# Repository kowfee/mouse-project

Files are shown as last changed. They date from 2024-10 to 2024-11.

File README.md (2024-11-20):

# mouse-diy
this project was inspired by https://github.com/wareya/DIY-Gaming-Mouse

!!!! ----- DO NOT CHANGE THE STRUCTURE OF THE FILES AND DIRECTORIES IN 'mouse-diy' ---- !!!!

!!!! ----- src/srom_3360_0x04.h should contain copyrighted material, so it is not included in this repository. 0x00 should be replaced with a correct sequence, available on the internet ---- !!!!
!!!! ----- it is firmware for the pmw3360 sensor. it will function without the firmware, however loses some of the functionality and precision ---- !!!!

[INSTALLATION]

- Windows: 
    - within the 'dist' folder run the "installer.exe"

- Linux: 
    - run the following commands from the 'mouse-diy' directory in the terminal:
        - chmod 744 bin/arduino-cli
        - chmod 744 dist/interface
        - bin/arduino-cli core install arduino:mbed_rp2040@4.1.5
        - sudo $HOME/.arduino15/packages/arduino/hardware/mbed_rp2040/4.1.5/post_install.sh
        - bin/arduino-cli config set library.enable_unsafe_install true
        - bin/arduino-cli lib install --zip-path files/Adafruit_NeoPixel-1.12.3.zip

[HOW TO USE]

- Windows:
    - run the 'interface.exe' within the 'dist' folder

- Linux:
    - from the 'mouse-diy' directory run the following command:
        - dist/interface

The user interface lets you choose how many DPI settings you want to save and the DPI for each setting. You can also adjust the RGB color for the static setting.

[UNINSTALL]

- Windows: 
    - run the following commands in CMD:
        - rmdir /s /q %USERPROFILE%\AppData\Local\Arduino15\packages\arduino\hardware\mbed_rp2040\
        - rmdir /s /q %USERPROFILE%\Documents\Arduino\libraries\Adafruit_NeoPixel\

- Linux:
    - run the following commands in the terminal:
        - rm -rf $HOME/.arduino15/packages/arduino/hardware/mbed_rp2040/
        - rm -rf $HOME/Arduino/libraries/Adafruit_Neopixel/

[LICENSE]
Adafruit NeoPixel is licensed under GNU Lesser General Public License https://github.com/adafruit/Adafruit_NeoPixel

Arduino CLI is licensed under GNU General Public License https://github.com/arduino/arduino-cli

relmouse_16.h is based on files from mbed OS, also licensed under the Apache License, version 2.0. https://github.com/arduino/ArduinoCore-mbed

The hardware design files ("PCB mit LED", "PCB_Fabrication_Files" "Fusion360-Base.f3z" and "Fusion360-Body.f3z") are licensed under the SolderpadLicense, version 2.1, as follows:
```
Copyright 2024 Pasty6969, klibandm, kowfee
SPDX-License-Identifier: Apache-2.0 WITH SHL-2.1

Licensed under the Solderpad Hardware License v 2.1 (the “License”); you may not use this file except in compliance with the License, or, at your option, the Apache License version 2.0. You may obtain a copy of the License at

https://solderpad.org/licenses/SHL-2.1/

Unless required by applicable law or agreed to in writing, any work distributed under the License is distributed on an “AS IS” BASIS, WITHOUT WARRANTIES OR CONDITIONS OF ANY KIND, either express or implied. See the License for the specific language governing permissions and limitations under the License.
```

mouse-diy.ino as well as other file contents are licensed under MIT License

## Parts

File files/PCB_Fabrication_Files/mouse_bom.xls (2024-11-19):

Comment | Designator | Footprint | JLCPCB Part #
ABM8-272-T3 | Y1 | Crystal_SMD_3225-4Pin_3.2x2.5mm | C50430
RP2040 | U3 | RP2040-QFN-56 | C2040
LM1117-1.8V | U1 | SOT-223-3_TabPin2 | C347220
100n | C7,C16,C6,C3,C11,C9,C13,C15,C500,C12,C14,C17 | C_0603_1608Metric | C14663
W25Q32JVSS | U4 | SOIC-8_5.275x5.275mm_P1.27mm | C97521
1u | C10,C8 | C_0603_1608Metric | C15849
D | D5,D3,D10,D6,D11,D9,D1,D4,D8,D12,D7,D2 | D_SOD-123 | C81598
R39 | R40 | R_0603_1608Metric | C23154
LED | LED1,LED2 | SK6812-EC20 | C2909058
15p | C200,C300 | C_0603_1608Metric | C1644
10k | R200,R1 | R_0603_1608Metric | C25804
NCP1117-3.3_SOT223 | U10 | SOT-223-3_TabPin2 | C6186
4.7uF | C4 | C_0603_1608Metric | C19666
1k | R500,R100 | R_0603_1608Metric | C21190
27 | R4,R3 | R_0603_1608Metric | C25190
10u | C400,C2,C100,C1 | C_0603_1608Metric | C19702

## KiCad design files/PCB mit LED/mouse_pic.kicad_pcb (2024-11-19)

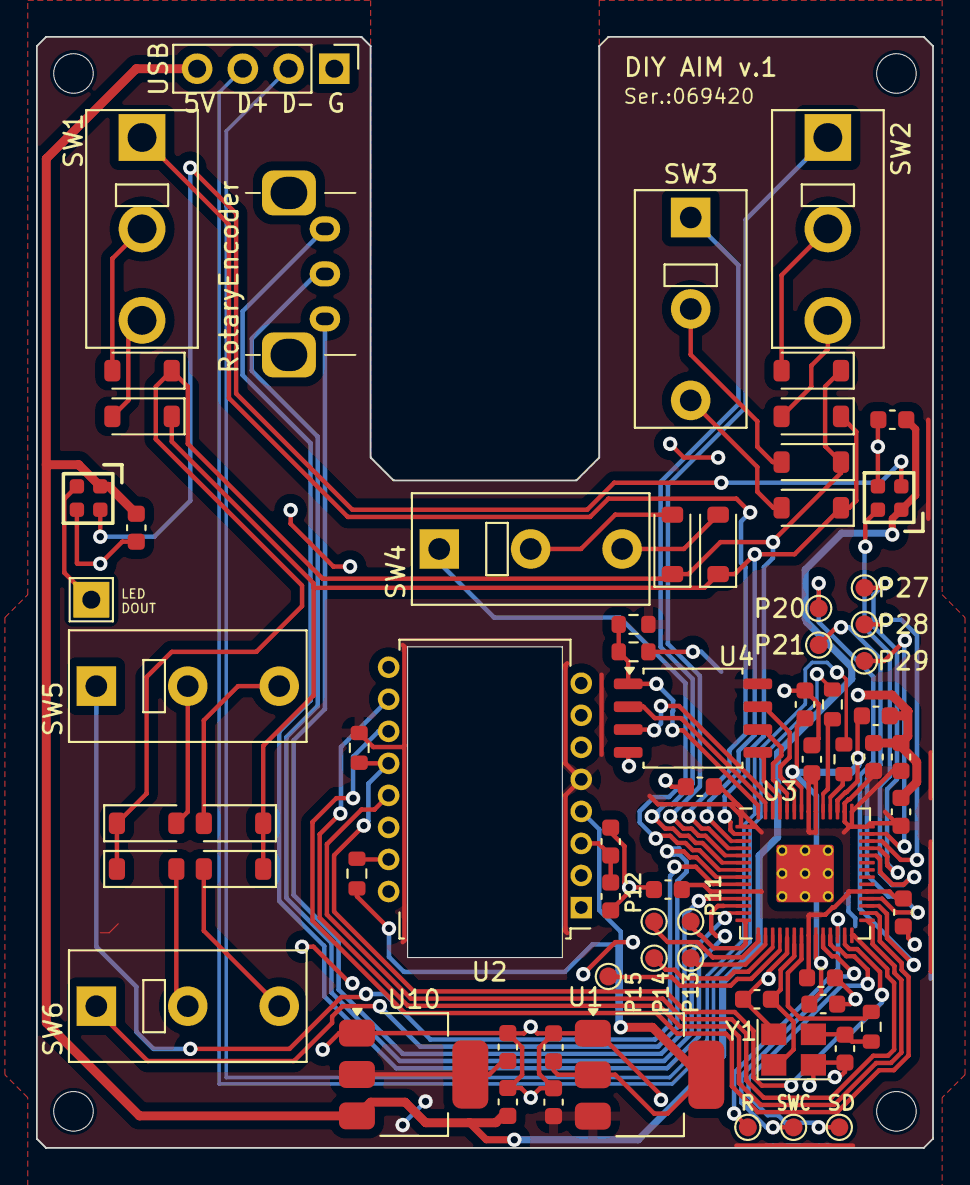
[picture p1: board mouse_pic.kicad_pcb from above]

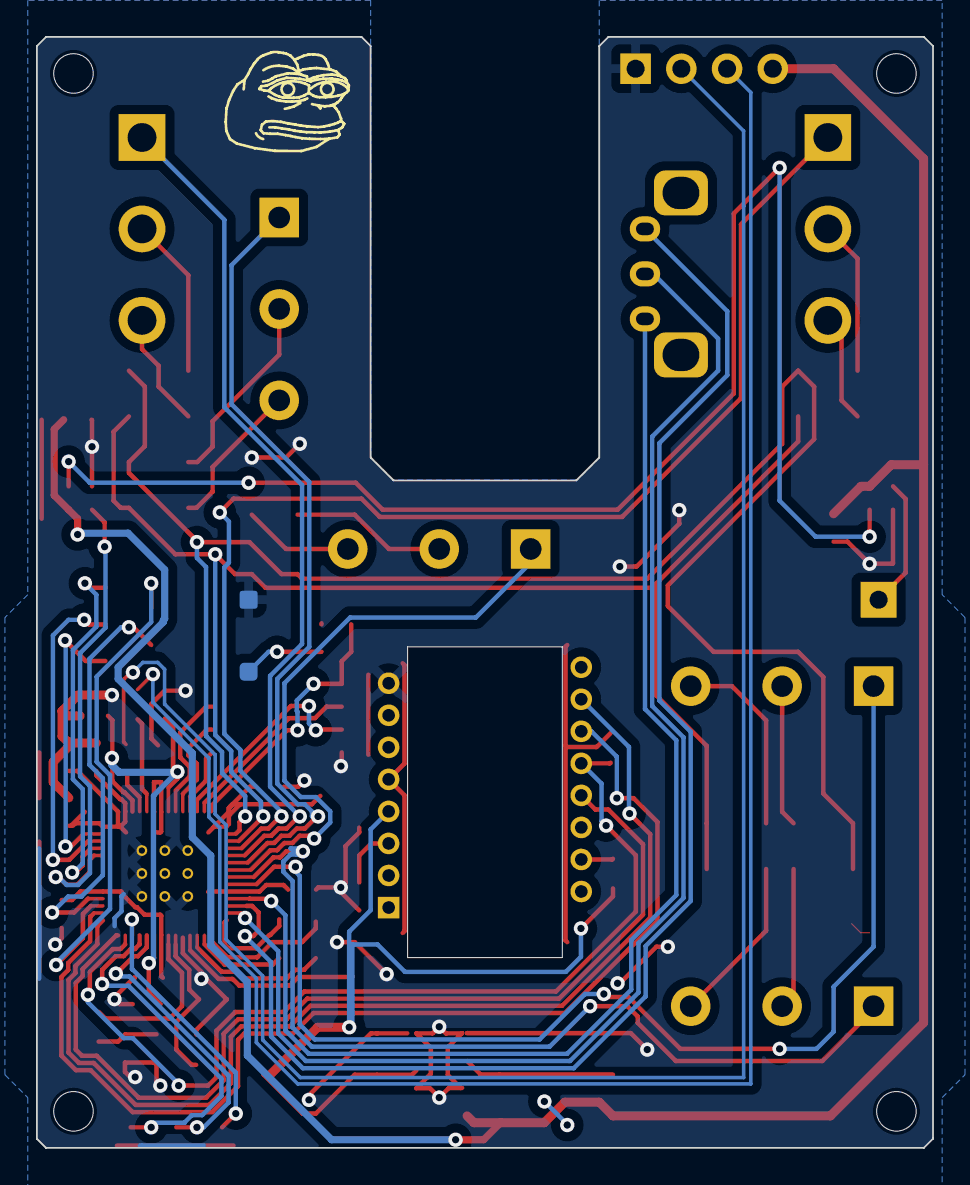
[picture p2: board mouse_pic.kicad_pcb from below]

Board: 2 copper layers, 49.8 x 61.7 mm, 72 parts (2 on the bottom side), 64 nets.

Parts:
C1, C2: 10uF; C_0603_1608Metric
C3: 100nF; C_0603_1608Metric
C4: 4.7uF; C_0603_1608Metric
C6, C7, C9, C11, C12, C13, C14, C15, C16, C17, C500: 100n; C_0603_1608Metric
C8, C10: 1u; C_0603_1608Metric
C100, C400: 10u; C_0603_1608Metric
C200, C300: 15p; C_0603_1608Metric
D1, D2, D3, D4, D5, D6, D7, D8, D9, D10, D11, D12: D; D_SOD-123
Encoder1: RotaryEncoder; Alps-EC10E1220501
LED1, LED2: LED_SK6812-EC20
LED_OUT1: DOUT; TestPoint_THTPad_2.0x2.0mm_Drill1.0mm
P11, P12, P13, P14, P15, P20, P21, P27, P28, P29, P30, P31, P32: TestPoint; TestPoint_Pad_D1.0mm
R1: 10K; R_0603_1608Metric
R3, R4: 27; R_0603_1608Metric
R40: R39; R_0603_1608Metric
R100, R500: 1k; R_0603_1608Metric
R200: 10k; R_0603_1608Metric
ResetGround: ResetGround
SW1, SW2, SW3, SW4, SW5, SW6: SW_SPDT; SW_Tactile_SPDT_Omron_D2F
U1: LM1117-1.8V; SOT-223-3_TabPin2
U2: PMW3360DM-T2QU; PixArt_PDIP-16_10.9x16.2mm_P1.78mm
U3: RP2040; RP2040-QFN-56
U4: W25Q32JVSS; SOIC-8_5.275x5.275mm_P1.27mm
U10: NCP1117-3.3_SOT223; SOT-223-3_TabPin2
USB1: USB; PinHeader_1x04_P2.54mm_Vertical
USB_BOOT1: Conn_01x01_Socket; TestPoint_THTPad_D2.0mm_Drill1.0mm_Edit
Y1: ABM8-272-T3; Crystal_SMD_3225-4Pin_3.2x2.5mm

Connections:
+1V1: C6.1, C7.1, C8.1, U3.23 (DVDD), U3.45 (VREG_VOUT), U3.50 (DVDD)
+3V3: C1.1, C9.1, C10.1, C11.1, C12.1, C13.1, C14.1, C15.1, C400.1, C500.1, R1.2, R200.1, U1.3 (VI), U2.5 (VDDIO), U3.1 (IOVDD), U3.10 (IOVDD), U3.22 (IOVDD), U3.33 (IOVDD), U3.42 (IOVDD), U3.43 (ADC_AVDD), U3.44 (VREG_IN), U3.48 (USB_VDD), U3.49 (IOVDD), U4.8 (VCC), U10.2 (VO)
/3360LED: R40.1, U2.15 (LED_P)
/ENC_A: Encoder1.A, U3.11 (GPIO8)
/ENC_B: Encoder1.B, U3.13 (GPIO10)
/ENC_C: Encoder1.C, U3.12 (GPIO9)
/GPIO0: D1.1 (K), D3.1 (K), D5.1 (K), D7.1 (K), D9.1 (K), D11.1 (K), U3.2 (GPIO0)
/GPIO1: D2.1 (K), D4.1 (K), D6.1 (K), D8.1 (K), D10.1 (K), D12.1 (K), U3.3 (GPIO1)
/GPIO2: SW1.2 (B), U3.4 (GPIO2)
/GPIO3: SW2.2 (B), U3.5 (GPIO3)
/GPIO4: SW3.2 (B), U3.6 (GPIO4)
/GPIO5: SW4.2 (B), U3.7 (GPIO5)
/GPIO6: SW6.2 (B), U3.8 (GPIO6)
/GPIO7: SW5.2 (B), U3.9 (GPIO7)
/GPIO11: P11.1, U3.14 (GPIO11)
/GPIO12: P12.1, U3.15 (GPIO12)
/GPIO13: P13.1, U3.16 (GPIO13)
/GPIO14: P14.1, U3.17 (GPIO14)
/GPIO15: P15.1, U3.18 (GPIO15)
/GPIO16: R1.1, U2.12 (MISO), U3.27 (GPIO16)
/GPIO17: U2.13 (NCS), U3.28 (GPIO17)
/GPIO18: U2.10 (SCLK), U3.29 (GPIO18)
/GPIO19: U2.11 (MOSI), U3.30 (GPIO19)
/GPIO20: P20.1, U3.31 (GPIO20)
/GPIO21: P21.1, U3.32 (GPIO21)
/GPIO26_ADC0: LED1.4 (DIN), U3.38 (GPIO26_ADC0)
/GPIO27_ADC1: P27.1, U3.39 (GPIO27_ADC1)
/GPIO28_ADC2: P28.1, U3.40 (GPIO28_ADC2)
/GPIO29_ADC3: P29.1, U3.41 (GPIO29_ADC3)
/QSPI_SCLK: U3.52 (QSPI_SCLK), U4.6 (CLK)
/QSPI_SD0: U3.53 (QSPI_SD0), U4.5 (DI(IO0))
/QSPI_SD1: U3.55 (QSPI_SD1), U4.2 (DO(IO1))
/QSPI_SD2: U3.54 (QSPI_SD2), U4.3 (IO2)
/QSPI_SD3: U3.51 (QSPI_SD3), U4.7 (IO3)
/QSPI_SS: R100.1, R200.2, U3.56 (QSPI_SS), U4.1 (~CS)
/RUN: P30.1, U3.26 (RUN)
/SWCLK: P31.1, U3.24 (SWCLK)
/SWD: P32.1, U3.25 (SWD)
/USBD+: R3.1, USB1.3
/USBD-: R4.1, USB1.2
/V2: C2.1, R40.2, U1.2 (VO), U2.4 (VDD)
/VDDPIX: C3.1, C4.1, U2.3 (VDDPIX)
/XIN: C200.1, U3.20 (XIN), Y1.1
/XOUT: R500.1, U3.21 (XOUT)
/~USB_BOOT: R100.2, USB_BOOT1.1
GND: C1.2, C2.2, C3.2, C4.2, C6.2, C7.2, C8.2, C9.2, C10.2, C11.2, C12.2, C13.2, C14.2, C15.2, C16.2, C17.2, C100.2, C200.2, C300.2, C400.2, C500.2, LED1.3 (GND), LED2.3 (GND), ResetGround.1, U1.1 (GND), U2.8 (GND), U3.19 (TESTEN), U3.57 (GND), U4.4 (GND), U10.1 (GND), USB1.1, Y1.2, Y1.4
unnamed: C300.1, R500.2, Y1.3
unnamed: D1.2 (A), SW1.1 (A)
unnamed: D2.2 (A), SW1.3 (C)
unnamed: D3.2 (A), SW2.1 (A)
unnamed: D4.2 (A), SW2.3 (C)
unnamed: D5.2 (A), SW3.1 (A)
unnamed: D6.2 (A), SW3.3 (C)
unnamed: D7.2 (A), SW4.1 (A)
unnamed: D8.2 (A), SW4.3 (C)
unnamed: D9.2 (A), SW5.1 (A)
unnamed: D10.2 (A), SW5.3 (C)
unnamed: D11.2 (A), SW6.1 (A)
unnamed: D12.2 (A), SW6.3 (C)
unnamed: LED1.2 (DOUT), LED2.4 (DIN)
unnamed: LED2.2 (DOUT), LED_OUT1.1
unnamed: R4.2, U3.46 (USB_DM)
unnamed: R3.2, U3.47 (USB_DP)
VBUS: C16.1, C17.1, C100.1, LED1.1 (VDD), LED2.1 (VDD), U10.3 (VI), USB1.4

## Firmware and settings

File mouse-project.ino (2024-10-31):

/*
 * Copyright (c) 2024, wareya
 * SPDX-License-Identifier: Apache-2.0
 *
 * Licensed under the Apache License, Version 2.0 (the "License");
 * you may not use this file except in compliance with the License.
 * You may obtain a copy of the License at
 *
 *     http://www.apache.org/licenses/LICENSE-2.0
 *
 * Unless required by applicable law or agreed to in writing, software
 * distributed under the License is distributed on an "AS IS" BASIS,
 * WITHOUT WARRANTIES OR CONDITIONS OF ANY KIND, either express or implied.
 * See the License for the specific language governing permissions and
 * limitations under the License.
 */

#include <SPI.h>
#include <mbed.h>


#include <Adafruit_NeoPixel.h>

// constants won't change. They're used here to 
// set pin numbers:
const int ledPin = 26;     // the number of the neopixel strip
const int numLeds = 2;

Adafruit_NeoPixel strip = Adafruit_NeoPixel(numLeds, ledPin, NEO_GRB + NEO_KHZ800);




REDIRECT_STDOUT_TO(Serial);

#include <PluggableUSBHID.h>

#include "src/srom_3360_0x04.h"
#include "src/relmouse_16.h"
USBMouse16 mouse(false);

#define REG_PRODUCT_ID (0x00)
#define REG_REVISION_ID (0x01)
#define REG_MOTION (0x02)
#define REG_DELTA_X_L (0x03)
#define REG_DELTA_X_H (0x04)
#define REG_DELTA_Y_L (0x05)
#define REG_DELTA_Y_H (0x06)
#define REG_SQUAL (0x07)
#define REG_RAW_DATA_SUM (0x08)
#define REG_MAX_RAW_DATA (0x09)
#define REG_MIN_RAW_DATA (0x0A)
#define REG_SHUTTER_LOWER (0x0B)
#define REG_SHUTTER_UPPER (0x0C)
#define REG_CONTROL (0x0D)

#define REG_CONFIG1 (0x0F)
#define REG_CONFIG2 (0x10)
#define REG_ANGLE_TUNE (0x11)
#define REG_FRAME_CAPTURE (0x12)
#define REG_SROM_ENABLE (0x13)
#define REG_RUN_DOWNSHIFT (0x14)
#define REG_REST1_RATE_LOWER (0x15)
#define REG_REST1_RATE_UPPER (0x16)
#define REG_REST1_DOWNSHIFT (0x17)
#define REG_REST2_RATE_LOWER (0x18)
#define REG_REST2_RATE_UPPER (0x19)
#define REG_REST2_DOWNSHIFT (0x1A)
#define REG_REST3_RATE_LOWER (0x1B)
#define REG_REST3_RATE_UPPER (0x1C)

#define REG_OBSERVATION (0x24)
#define REG_DATA_OUT_LOWER (0x25)
#define REG_DATA_OUT_UPPER (0x26)

#define REG_RAW_DATA_DUMP (0x29)
#define REG_SROM_ID (0x2A)
#define REG_MIN_SQ_RUN (0x2B)
#define REG_RAW_DATA_THRESHOLD (0x2C)

#define REG_CONFIG5 (0x2F)

#define REG_POWER_UP_RESET (0x3A)
#define REG_SHUTDOWN (0x3B)

#define REG_INVERSE_PRODUCT_ID (0x3F)

#define REG_LIFTCUTOFF_TUNE3 (0x41)
#define REG_ANGLE_SNAP (0x42)

#define REG_LIFTCUTOFF_TUNE1 (0x4A)

#define REG_MOTION_BURST (0x50)

#define REG_LIFTCUTOFF_TUNE_TIMEOUT (0x58)

#define REG_LIFTCUTOFF_TUNE_MIN_LENGTH (0x5A)

#define REG_SROM_LOAD_BURST (0x62)
#define REG_LIFT_CONFIG (0x63)
#define REG_RAW_DATA_BURST (0x64)
#define REG_LIFTOFF_TUNE2 (0x65)

#define CONFIG2_REST_ENABLED (0x30)
#define CONFIG2_REPORT_MODE (0x04)


#define BUTTONS_ON 0
#define BUTTONS_OFF 1

#define BUTTON_M1 2
#define BUTTON_M2 3
#define BUTTON_M3 4
#define BUTTON_M4 6
#define BUTTON_M5 7
#define BUTTON_DPI 5

#define ENCODER_A 8
#define ENCODER_B 10
#define ENCODER_COM 9

#define PIN_NCS 17
#define PIN_MOSI 19
#define PIN_MISO 16

SPISettings spisettings(2000000, MSBFIRST, SPI_MODE3);
MbedSPI spi(PIN_MISO, PIN_MOSI, 18);

void setup_buttons()
{
    pinMode(BUTTONS_OFF, INPUT);
    pinMode(BUTTONS_ON, INPUT);
    pinMode(BUTTON_M1, INPUT_PULLUP);
    pinMode(BUTTON_M2, INPUT_PULLUP);
    pinMode(BUTTON_M3, INPUT_PULLUP);
    pinMode(BUTTON_M4, INPUT_PULLUP);
    pinMode(BUTTON_M5, INPUT_PULLUP);
    pinMode(BUTTON_DPI, INPUT_PULLUP);
    
    pinMode(ENCODER_A, INPUT_PULLUP);
    pinMode(ENCODER_B, INPUT_PULLUP);
    pinMode(ENCODER_COM, OUTPUT);
    
    digitalWrite(ENCODER_COM, LOW);
}

void setup()
{
    Serial1.begin(1000000);
    
    delay(3000);
    
    // SCK, MISO, MOSI, SS
    SPI.begin();
    pinMode(PIN_NCS, OUTPUT);
    
    digitalWrite(PIN_NCS, HIGH);
    delayMicroseconds(1);
    digitalWrite(PIN_NCS, LOW);
    delayMicroseconds(1);
    digitalWrite(PIN_NCS, HIGH);
    delayMicroseconds(1);
    
    pmw3360_boot();
    
    delay(10);
    
    pmw3360_config(15);
    
    setup_buttons();
    strip.begin();
    strip.setBrightness(80); // 1/3 brightness
}

uint32_t pins_state = 0;
uint8_t buttons = 0;
// 8ms latch time
uint8_t buttons_latch_max = 8;
uint8_t buttons_latch[5] = {0, 0, 0, 0, 0};

int dpi_values[] = {6};
int NUM_DPI_VALUES = sizeof(dpi_values) / sizeof(dpi_values[0]);
int current_dpi_index = 0;

#define GLOBAL_BRIGHTNESS 10
int rgb_modes[] = {0, 1, 2, 3, 4};
// 0 - off; 1 - static color; 2 - rainbow; 3 - police; 4 - breathing
int NUM_RGB_MODES = sizeof(rgb_modes) / sizeof(rgb_modes[0]);
int rgb_selector = 1;


volatile uint32_t * pad_control = (uint32_t *)0x4001c000;
volatile uint32_t * gpio_oe_set = (uint32_t *)0xd0000024;
volatile uint32_t * gpio_oe_clr = (uint32_t *)0xd0000028;
volatile uint32_t * gpio_in = (uint32_t *)0xd0000004;

void test() {
    // Your test function implementation here
}

void update_buttons() {
    /*
    // disable pullup/pulldown
    pad_control[BUTTONS_OFF + 1] &= 0xFFFFFFF2;
    pad_control[BUTTONS_ON + 1] &= 0xFFFFFFF2;
    */
    
    // change BUTTONS_OFF to high impedance and BUTTONS_ON to output
    // using pinMode for this is way, WAY too slow, like 50us per call (?!?!?!)
    *gpio_oe_clr = 1 << BUTTONS_OFF;
    *gpio_oe_set = 1 << BUTTONS_ON;
    
    // read ON pins
    digitalWrite(BUTTONS_ON, LOW);
    delayMicroseconds(1);
    uint32_t pins_on = ~*gpio_in;
    
    // change BUTTONS_OFF to high impedance and BUTTONS_ON to output
    *gpio_oe_set = 1 << BUTTONS_OFF;
    *gpio_oe_clr = 1 << BUTTONS_ON;
    
    // read OFF pins
    digitalWrite(BUTTONS_OFF, LOW);
    delayMicroseconds(1);
    uint32_t pins_off = ~*gpio_in;
    
    // update pin state
    // treat middle state (on-off matching) as no-update (use previous state)
    uint32_t pins_update = pins_on ^ pins_off;
    pins_state = (pins_state & (~pins_update)) | (pins_on & pins_update);
    
    // update button state
    uint8_t next_buttons =
          ((!!(pins_state & (1 << BUTTON_M1))))
        | ((!!(pins_state & (1 << BUTTON_M2))) << 1)
        | ((!!(pins_state & (1 << BUTTON_M3))) << 2)
        | ((!!(pins_state & (1 << BUTTON_M4))) << 3)
        | ((!!(pins_state & (1 << BUTTON_M5))) << 4);
    
    // handle latch
    uint8_t ok_mask = 
          ((buttons_latch[0] == 0))
        | ((buttons_latch[1] == 0) << 1)
        | ((buttons_latch[2] == 0) << 2)
        | ((buttons_latch[3] == 0) << 3)
        | ((buttons_latch[4] == 0) << 4);
    
    next_buttons = (next_buttons & ok_mask) | (buttons & ~ok_mask);
    
    // update latch timings
    for (int i = 0; i < 5; i++) {
        if (((next_buttons ^ buttons) >> i) & 1)
            buttons_latch[i] = buttons_latch_max;
        else if (buttons_latch[i])
            buttons_latch[i] -= 1;
    }
    
    static bool dpi_button_pressed = false;
    static uint32_t dpi_button_press_time = 0;
    static const uint32_t HOLD_THRESHOLD = 2000; // 2 seconds

    // Detect BUTTON_DPI press and release (state change)
    bool current_dpi_state = pins_state & (1 << BUTTON_DPI);


    if ((!dpi_button_pressed) && (current_dpi_state))
    {
        // Button was just pressed
        dpi_button_pressed = true;
        dpi_button_press_time = millis(); // Track time of button press
    }
    else if ((dpi_button_pressed) && (millis() - dpi_button_press_time >= HOLD_THRESHOLD) && (!current_dpi_state))
    {
        rgb_selector = (rgb_selector + 1) % NUM_RGB_MODES;
        dpi_button_press_time = millis(); // Reset the press time to avoid multiple calls
        dpi_button_pressed = false;
    }
    else if ((dpi_button_pressed) && (!current_dpi_state))
    {
        // Button was just released
        dpi_button_pressed = false;

        // Cycle through dpi values
        current_dpi_index = (current_dpi_index + 1) % NUM_DPI_VALUES;
        int new_dpi_value = dpi_values[current_dpi_index];

        // Call the configuration function with the new DPI value
        pmw3360_config(new_dpi_value);
    }

    buttons = next_buttons;
}


uint8_t wheel_state_a = 0;
uint8_t wheel_state_b = 0;
uint8_t wheel_state_output = 0;
int8_t wheel_progress = 0;

void update_wheel()
{
    uint8_t wheel_new_a = digitalRead(ENCODER_A);
    uint8_t wheel_new_b = digitalRead(ENCODER_B);
    
    if (wheel_new_a != wheel_state_a || wheel_new_b != wheel_state_b)
    {
        if (wheel_new_a == wheel_new_b && wheel_state_output != wheel_new_a)
        {
            // when scrolling up, B changes first. when scrolling down, A changes first
            if (wheel_new_b == wheel_state_b)
                wheel_progress += 1;
            // the wheel can glitch and jump straight from 00 to 11 (or vice versa)
            // so we need to check that only one state has changed since the last test
            else if(wheel_new_a == wheel_state_a)
                wheel_progress -= 1;
            
            wheel_state_output = wheel_new_a;
        }
        
        wheel_state_a = wheel_new_a;
        wheel_state_b = wheel_new_b;
    }
}


unsigned long previousMillis = 0; // stores the last time LEDs were updated
const long interval = 30;         // interval at which to update LEDs (milliseconds)

uint16_t j = 0;


void rgb_select(int rgb_selector) {
  switch (rgb_modes[rgb_selector])
  {
  case 0:
    rgb_off();
    break;        
  case 1:
    strip.setBrightness(GLOBAL_BRIGHTNESS);
    static_color();
    break;
  case 2:
    strip.setBrightness(GLOBAL_BRIGHTNESS);
    rainbow();
    break;
  case 3:
    strip.setBrightness(GLOBAL_BRIGHTNESS);
    police();
    break;
  case 4:
    breathing();
    break;
  }
}

void rgb_off() {
  for (int i = 0; i < strip.numPixels(); i++) {
	  strip.setPixelColor(i, 0, 0, 0);
  }
  strip.show();
}

void static_color() {
  for (int i = 0; i < strip.numPixels(); i++) {
	strip.setPixelColor(i, 217, 20, 217);
  }
  strip.show();
}

void rainbow() {
  uint16_t i;

  for(i = 0; i < strip.numPixels(); i++) {
    strip.setPixelColor(i, RainbowWheel((i * 1 + j) & 255));
  }
  strip.show();

  j++;
  if (j >= 256) {
    j = 0;
  }
}

uint32_t RainbowWheel(byte WheelPos) {
  if(WheelPos < 85) {
    return strip.Color(WheelPos * 3, 255 - WheelPos * 3, 0);
  } 
  else if(WheelPos < 170) {
    WheelPos -= 85;
    return strip.Color(255 - WheelPos * 3, 0, WheelPos * 3);
  } 
  else {
    WheelPos -= 170;
    return strip.Color(0, WheelPos * 3, 255 - WheelPos * 3);
  }
}

uint16_t police_flag = 0;
static uint32_t blink_time = 0;
static const uint32_t BLINK_THRESHOLD = 500;

void police() {
  if((millis() - blink_time >= BLINK_THRESHOLD) && (police_flag == 0)) {
    blink_time = millis();
    strip.setPixelColor(0, 255, 0, 0);
    strip.setPixelColor(1, 0, 0, 255);
    police_flag=(police_flag + 1) % 2;
  }
  else if((millis() - blink_time >= BLINK_THRESHOLD) && (police_flag == 1)) {
    blink_time = millis();
    strip.setPixelColor(0, 0, 0, 255);
    strip.setPixelColor(1, 255, 0, 0);
    police_flag= (police_flag + 1) % 2;
  }
  strip.show();
}

uint32_t colors[] = {
  strip.Color(255, 0, 0),
  strip.Color(0, 255, 0),
  strip.Color(0, 0, 255),
  strip.Color(255, 255, 0),
  strip.Color(0, 255, 255),
  strip.Color(255, 0, 255)
};

int num_colors = sizeof(colors) / sizeof(colors[0]);
int currentColorIndex = 0;
int fade_brightness = 0;
int fadeAmount = 5;

void breathing() {
  strip.setPixelColor(0, colors[currentColorIndex]);
  strip.setPixelColor(1, colors[currentColorIndex]);
  strip.setBrightness(fade_brightness);
  strip.show();
  fade_brightness += fadeAmount;
  if (fade_brightness <= 0 || fade_brightness >= 255) {
    fadeAmount = -fadeAmount;
    if (fade_brightness <= 0) {
      currentColorIndex = (currentColorIndex + 1) % num_colors;
    }
  }
}

int n = 0;
int usb_hid_poll_interval = 1; 

struct MotionBurstData {
    uint8_t motion;
    uint8_t observation;
    int16_t x;
    int16_t y;
    uint8_t squal;
    uint8_t raw_sum;
    uint8_t raw_max;
    uint8_t raw_min;
    uint16_t shutter;
};

MotionBurstData spi_read_motion_burst(bool do_update_wheel);

void loop()
{
    unsigned long currentMillis = millis();
    if (currentMillis - previousMillis >= interval) {
      previousMillis = currentMillis;
      rgb_select(rgb_modes[rgb_selector]);
    }

    // these execute nearly instantly
    // we want to call update_wheel roughly every 250ms to avoid skipping
    update_wheel();
    delayMicroseconds(250);
    update_wheel();
    
    int16_t x = 0;
    int16_t y = 0;
    
    // takes ~400us to execute; wheel is updated again around 250ms into the call
    MotionBurstData data = spi_read_motion_burst(true);
    if (data.motion)
    {
        x = data.x;
        y = data.y;
    }
    
    update_wheel();
    update_buttons();
    
    int8_t wheel = wheel_progress;
    wheel_progress = 0;
    
    //uint32_t a = micros();
    // this will return around 1ms after the last time it returned
    // which should be around 250us from now
    mouse.update(x, y, buttons, wheel);
    //uint32_t b = micros();
    //Serial.println(b - a);
}

void pmw3360_boot()
{
    spi_write(REG_POWER_UP_RESET, 0x5A);
    delay(50);
    
    spi_read(0x02);
    spi_read(0x03);
    spi_read(0x04);
    spi_read(0x05);
    spi_read(0x06);
    
    srom_upload();
}

void pmw3360_config(int dpi_value)
{
    spi_write(REG_CONFIG1, dpi_value); // 1200 dpi
    
    // 3mm liftoff (2mm is bad for 3d printed case tolerances)
    // FIXME: make configurable
    //spi_write(REG_LIFT_CONFIG, 3);
}

void spi_begin()
{
    SPI.beginTransaction(spisettings);
}
void spi_end()
{
    SPI.endTransaction();
}

void spi_write(byte addr, byte data)
{
    spi_begin();
    
    digitalWrite(PIN_NCS, LOW);
    delayMicroseconds(1); // 120 nanoseconds; t_NCS-SCLK
    
    SPI.transfer(addr | 0x80);
    SPI.transfer(data);
    
    delayMicroseconds(35); // t_SCLK-NCS(write)
    digitalWrite(PIN_NCS, HIGH);
    
    spi_end();
    
    delayMicroseconds(180); // max(t_SWW, t_SWR)
}

byte spi_read(byte addr)
{
    spi_begin();
    
    digitalWrite(PIN_NCS, LOW);
    delayMicroseconds(1); // 120 nanoseconds; t_NCS-SCLK
    
    SPI.transfer(addr & 0x7F);
    
    delayMicroseconds(160); // t_SRAD
    
    byte ret = SPI.transfer(0);
    
    delayMicroseconds(1); // 120 nanoseconds; t_SCLK-NCS(read)
    digitalWrite(PIN_NCS, HIGH);
    
    spi_end();
    
    delayMicroseconds(20); // max(t_SRW, t_SRR)
    
    return ret;
}

MotionBurstData spi_read_motion_burst(bool do_update_wheel)
{
    MotionBurstData ret = {0};
    
    // this takes around 260ms to execute; update scroll wheel again after calling it
    spi_write(REG_MOTION_BURST, 0x00);
    if (do_update_wheel)
        update_wheel();
    
    spi_begin();
    
    digitalWrite(PIN_NCS, LOW);
    delayMicroseconds(1); // 120 nanoseconds; t_NCS-SCLK
    
    SPI.transfer(REG_MOTION_BURST);
    
    delayMicroseconds(35); // t_SRAD_MOTBR
    
    ret.motion = SPI.transfer(0);
    ret.observation = SPI.transfer(0);
    ret.x = SPI.transfer(0);
    ret.x |= ((uint16_t)SPI.transfer(0)) << 8;
    ret.y = SPI.transfer(0);
    ret.y |= ((uint16_t)SPI.transfer(0)) << 8;
    ret.squal = SPI.transfer(0);
    // don't care about the rest; terminate
    digitalWrite(PIN_NCS, HIGH);
    delayMicroseconds(1); // t_BEXIT = 500ns; wait 1000ns (1us)
    
    /*
    ret.raw_sum = SPI.transfer(0);
    ret.raw_max = SPI.transfer(0);
    ret.raw_min = SPI.transfer(0);
    ret.shutter = SPI.transfer(0);
    ret.shutter |= ((uint16_t)SPI.transfer(0)) << 8;
    */
    
    spi_end();
    
    return ret;
}

void srom_upload()
{
    spi_write(REG_CONFIG2, 0x00);
    spi_write(REG_SROM_ENABLE, 0x1D);
    delay(10);
    
    spi_write(REG_SROM_ENABLE, 0x18);
    
    spi_begin();
    
    digitalWrite(PIN_NCS, LOW);
    delayMicroseconds(1);
    
    SPI.transfer(REG_SROM_LOAD_BURST | 0x80);
    delayMicroseconds(15);
    
    for(size_t i = 0; i < SROM_LENGTH; i += 1)
    {
        SPI.transfer(srom[i]);
        delayMicroseconds(15);
    }
    
    digitalWrite(PIN_NCS, HIGH);
    delayMicroseconds(1);
    
    spi_end();
    
    delayMicroseconds(200);
    
    byte id = spi_read(REG_SROM_ID);
    printf("\n");
    printf("srom id: ");
    printf("%d", id);
    printf("\n");
    
    spi_write(REG_CONFIG2, 0x00);
}

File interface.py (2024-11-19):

import subprocess
from tkinter import *
from tkinter import ttk
from tkinter import colorchooser
from sys import platform
import serial.tools.list_ports

def getValues():
    with open("./mouse-diy.ino", "r") as ino_read:
        inoLines = ino_read.readlines()

    nDPI = numberOfDPIs.get()
    s1 = ent1.get()
    s2 = ent2.get()
    s3 = ent3.get()
    s4 = ent4.get()
    s5 = ent5.get()

    if s1 != '' :
        i1 = int(s1)
        nDPI1 = int((i1/100)-1)
    if s2 != '' :
        i2 = int(s2)
        nDPI2 = int((i2/100)-1)
    if s3 != '' :
        i3 = int(s3)
        nDPI3 = int((i3/100)-1)
    if s4 != '' :
        i4 = int(s4)
        nDPI4 = int((i4/100)-1)
    if s5 != '' :
        i5 = int(s5)
        nDPI5 = int((i5/100)-1)

    with open("./mouse-diy.ino", "w") as ino_write:
        rgb_mode = modeRGBbox.get()
        rgb_color = colorRGB
        brightness = brightnessValue.get()

        red: int
        green: int
        blue: int

        if rgb_mode != 'Static':
            red = 0
            green = 0
            blue = 0
        else:
            red = rgb_color[0]
            green = rgb_color[1]
            blue = rgb_color[2]

        inoLines[184] = f"#define GLOBAL_BRIGHTNESS {brightness}\n"

        if nDPI == 1:
            inoLines[180] = f"int dpi_values[] = {{{nDPI1}}};\n"
        elif nDPI == 2:
            inoLines[180] = f"int dpi_values[] = {{{nDPI1}, {nDPI2}}};\n"
        elif nDPI == 3:
            inoLines[180] = f"int dpi_values[] = {{{nDPI1}, {nDPI2}, {nDPI3}}};\n"
        elif nDPI == 4:
            inoLines[180] = f"int dpi_values[] = {{{nDPI1}, {nDPI2}, {nDPI3}, {nDPI4}}};\n"
        elif nDPI == 5:
            inoLines[180] = f"int dpi_values[] = {{{nDPI1}, {nDPI2}, {nDPI3}, {nDPI4}, {nDPI5}}};\n"

        if rgb_mode == "Off":
            inoLines[188] = f"int rgb_selector = 0;\n"
        elif rgb_mode == "Static":
            inoLines[188] = f"int rgb_selector = 1;\n"
            inoLines[364] = f"\tstrip.setPixelColor(i, {red}, {green}, {blue});\n"
        elif rgb_mode == "Rainbow":
            inoLines[188] = f"int rgb_selector = 2;\n"
        elif rgb_mode == "Police":
            inoLines[188] = f"int rgb_selector = 3;\n"
        elif rgb_mode == "Breathing":
            inoLines[188] = f"int rgb_selector = 4;\n"

        ino_write.writelines(inoLines)

    uploadToBoard()

def uploadToBoard():
    ports = list(serial.tools.list_ports.comports())
    for p in ports:
        if "2E8A:00C0" in p.hwid:
            arduino_port = p.device
    if checkBoardConnection():
        if platform == "win32" or platform == "win64":
            subprocess.run(["arduino-cli.exe", "compile", "--fqbn", "arduino:mbed_rp2040:pico",  "--port", arduino_port, "--upload", "./mouse-diy.ino"])
        elif platform == "linux" or platform == "linux2":
            subprocess.run(["./bin/arduino-cli", "compile", "--fqbn", "arduino:mbed_rp2040:pico",  "--port", arduino_port, "--upload", "./mouse-diy.ino"])
    else:
        ErrorWindow()

def checkValues(*args):
    dpi1 = ent1.get()
    dpi2 = ent2.get()
    dpi3 = ent3.get()
    dpi4 = ent4.get()
    dpi5 = ent5.get()
    nDPI = numberOfDPIs.get()
    color = colorRGB
    mode = modeRGBbox.get()
    scale = brightnessValue.get()

    saveSettings.config(state=DISABLED)

    rgbValidation = (mode != "Static" and color == ()) or (mode == "Static" and color != ()) or (mode != "Static" and color != ())
    dpiValidation = ((nDPI == 5 and dpi1 != "" and dpi2 != "" and dpi3 != "" and dpi4 != "" and dpi5 != "")
                        or (nDPI == 4 and dpi1 != "" and dpi2 != "" and dpi3 != "" and dpi4 != "")
                            or (nDPI == 3 and dpi1 != "" and dpi2 != "" and dpi3 != "")
                                or (nDPI == 2 and dpi1 != "" and dpi2 != "")
                                    or (nDPI == 1 and dpi1 != "") )

    if dpiValidation and rgbValidation:
        saveSettings.config(state="normal")
    else:
        saveSettings.config(state=DISABLED)

    if mode == 'Off' or mode == 'Breathing':
        brightnessValue.config(from_=0)
        brightnessValue.set(0)
        brightnessValue.config(state=DISABLED)
    else:
        brightnessValue.config(state="normal", from_=10)
        if scale != 0:
            brightnessValue.set(scale)
        else:
            brightnessValue.set(100)

    if mode == "Static" and colorRGB != ():
        colorFrame.config(bg=('#%02x%02x%02x' % (colorRGB)))
    else:
        colorFrame.config(bg=lab1['bg'])

def addDPI(*args):
    n = numberOfDPIs.get()

    if n == 1:
        ent1.config(state="readonly", style= "whiteBG.TCombobox")
        ent2.set("")
        ent2.config(state="disabled", style="TCombobox")
        ent3.set("")
        ent3.config(state="disabled", style="TCombobox")
        ent4.set("")
        ent4.config(state="disabled", style="TCombobox")
        ent5.set("")
        ent5.config(state="disabled", style="TCombobox")
    elif n == 2:
        ent1.config(state="readonly", style= "whiteBG.TCombobox")
        ent2.config(state="readonly", style= "whiteBG.TCombobox")
        ent3.set("")
        ent3.config(state="disabled", style="TCombobox")
        ent4.set("")
        ent4.config(state="disabled", style="TCombobox")
        ent5.set("")
        ent5.config(state="disabled", style="TCombobox")
    elif n == 3:
        ent1.config(state="readonly", style= "whiteBG.TCombobox")
        ent2.config(state="readonly", style= "whiteBG.TCombobox")
        ent3.config(state="readonly", style= "whiteBG.TCombobox")
        ent4.set("")
        ent4.config(state="disabled", style="TCombobox")
        ent5.set("")
        ent5.config(state="disabled", style="TCombobox")
    elif n == 4:
        ent1.config(state="readonly", style= "whiteBG.TCombobox")
        ent2.config(state="readonly", style= "whiteBG.TCombobox")
        ent3.config(state="readonly", style= "whiteBG.TCombobox")
        ent4.config(state="readonly", style= "whiteBG.TCombobox")
        ent5.set("")
        ent5.config(state="disabled", style="TCombobox")
    elif n == 5:
        ent1.config(state="readonly", style= "whiteBG.TCombobox")
        ent2.config(state="readonly", style= "whiteBG.TCombobox")
        ent3.config(state="readonly", style= "whiteBG.TCombobox")
        ent4.config(state="readonly", style= "whiteBG.TCombobox")
        ent5.config(state="readonly", style= "whiteBG.TCombobox")
    else:
        ent1.set("")
        ent1.config(state="disabled", style="TCombobox")
        ent2.set("")
        ent2.config(state="disabled", style="TCombobox")
        ent3.set("")
        ent3.config(state="disabled", style="TCombobox")
        ent4.set("")
        ent4.config(state="disabled", style="TCombobox")
        ent5.set("")
        ent5.config(state="disabled", style="TCombobox")
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

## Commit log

2024-07-18 Update 3360_Mouse_pico.ino
    improved dpi button "if" statement to better register the button press
2024-07-23 Add files via upload
    added rgb:
    function rgb_select() calls the appropriate rgb mode
    function rainbow() switches colors in a rainbow pattern
    function static_color() sets led to a static color
    changed if statement for dpi_button in update_buttons() to act as an rgb switch as well as the dpi switch. must be held 2 seconds
2024-08-12 insert dpi .ino file
2024-08-13 add switch case in .ino + add change mode select in .ino file
2024-10-31 fix bugs + add check if board is connected
    [mouse-project.ino, script.py]
